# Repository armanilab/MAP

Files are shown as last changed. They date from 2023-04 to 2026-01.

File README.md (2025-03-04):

<<<<<<< HEAD
# MAgnetoPhotometer (MAP)

> Details on system design and full assembly instructions can be found in the preprint: https://arxiv.org/abs/2401.01903

Ready to print 3D files can be found in CAD/stl_files.

The code to be uploaded to the Feather microcontroller can be found in code/MAP_main. 

Visual Data Analysis Program still in progress!

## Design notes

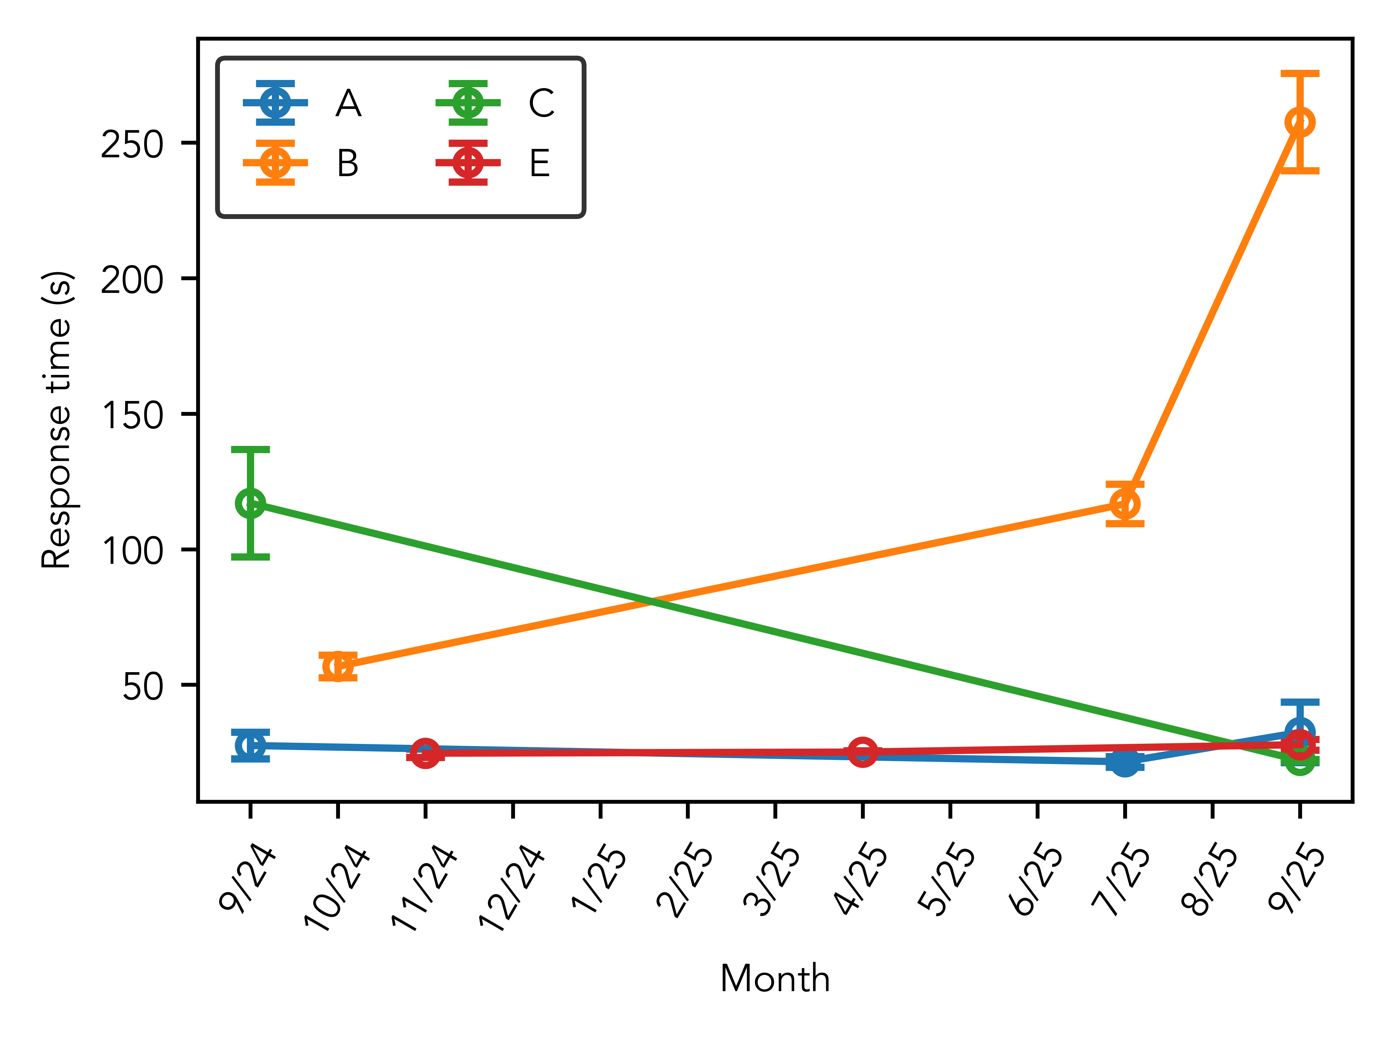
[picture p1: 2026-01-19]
code/model-4.0/plot_resp_times_1.0.png

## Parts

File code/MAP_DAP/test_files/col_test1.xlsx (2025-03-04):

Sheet: Sheet1
File_name | File_location | Date | Daily-num | User | sample | maGnet | Trial-num | Series-tags | Time | Magnet-time | System | Notes
example1 | paper_data/armando-paper | 2022.11.21 |  |  | s1 | 3 | 2 |  | 10:00 | 0:15 | OG | originally named: 3_3_t2 from directory 2022.11.21_working_range_t2
example2 | paper_data/armando-paper | 2022.11.21 |  |  | s2 | 3 | 2 |  | 10:00 | 0:15 | OG | originally named: 4_3_t2 from directory 2022.11.21_working_range_t2

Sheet: samples
ID | Owner | Material | Density | Batch-date | Solvent | Concentration | Dilution-date | Prep-date
s1 | Lexie | Iron oxide |  |  | Water | 0.1
s2 | Arlo | Dynabeads |  |  | PBS | 0.2

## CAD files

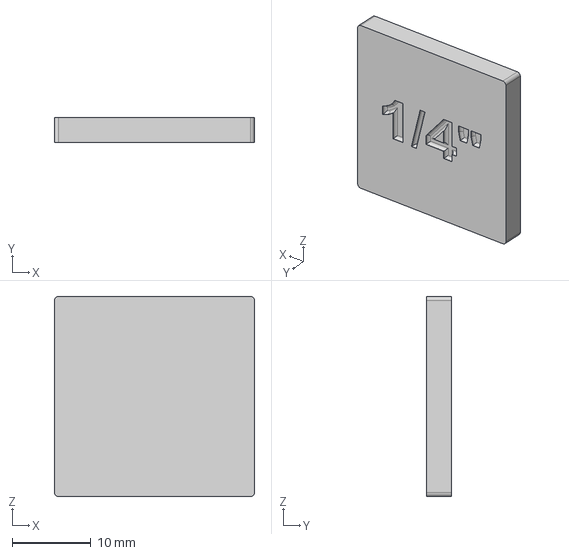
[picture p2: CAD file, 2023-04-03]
CAD/MAP_STEP_files/Magnet_Spacer_1-4.step
25.4 x 3.17 x 25.4 mm

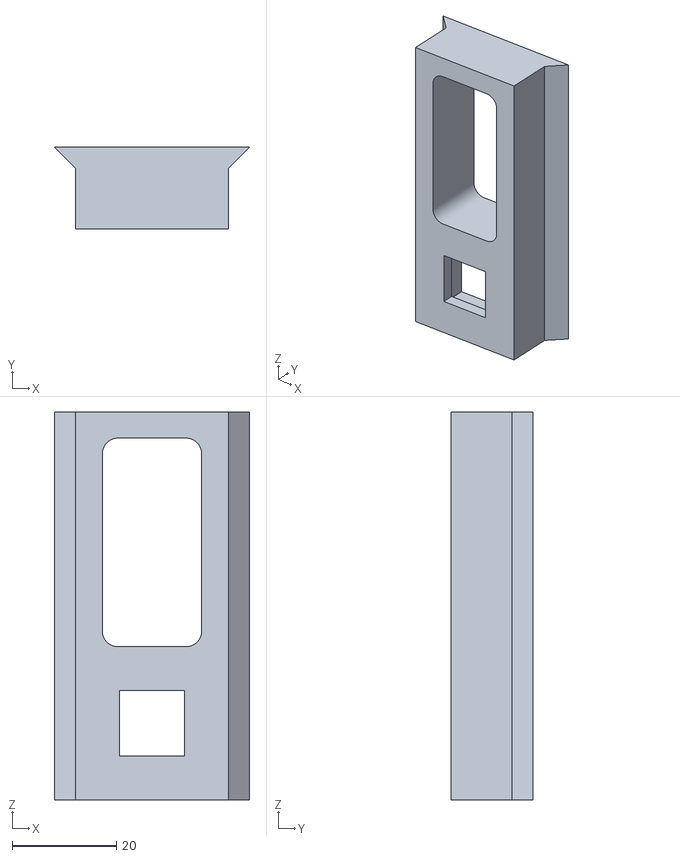
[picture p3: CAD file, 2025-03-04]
CAD/STL/magnet_slider_v1.stl
37.4 x 15.7 x 74.4

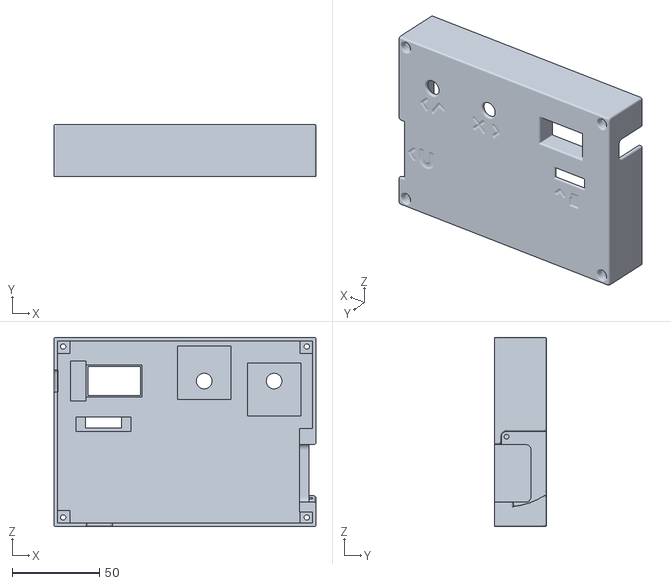
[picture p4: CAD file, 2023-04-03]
CAD/stl_files/top_panel.stl
150.0 x 30.0 x 108.3

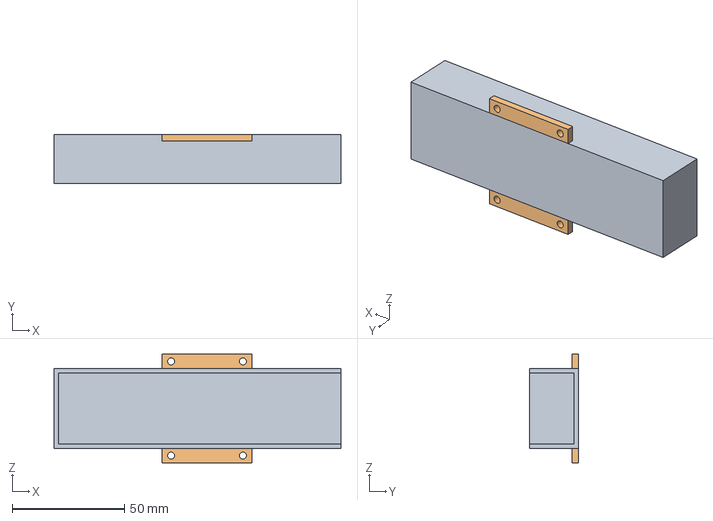
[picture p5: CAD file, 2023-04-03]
CAD/MAP_STEP_files/Magnet_Storage_Cover.step
128.0 x 22.0 x 48.5 mm

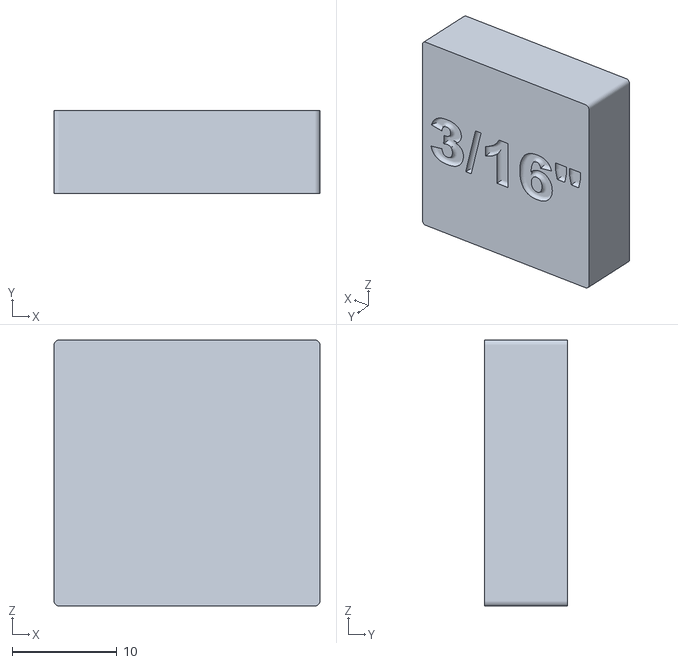
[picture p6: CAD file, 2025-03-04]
CAD/STL/magnet_spacer_3-16_v1.stl
25.4 x 7.94 x 25.4

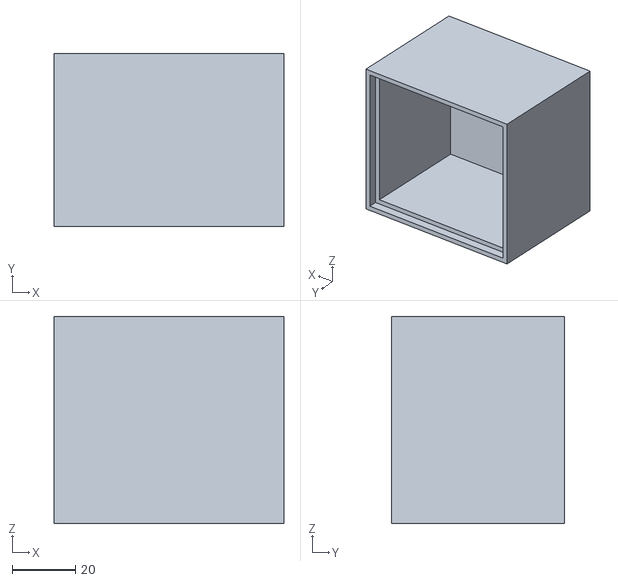
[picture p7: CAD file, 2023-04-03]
CAD/stl_files/stage_cover.stl
73.0 x 55.0 x 65.8

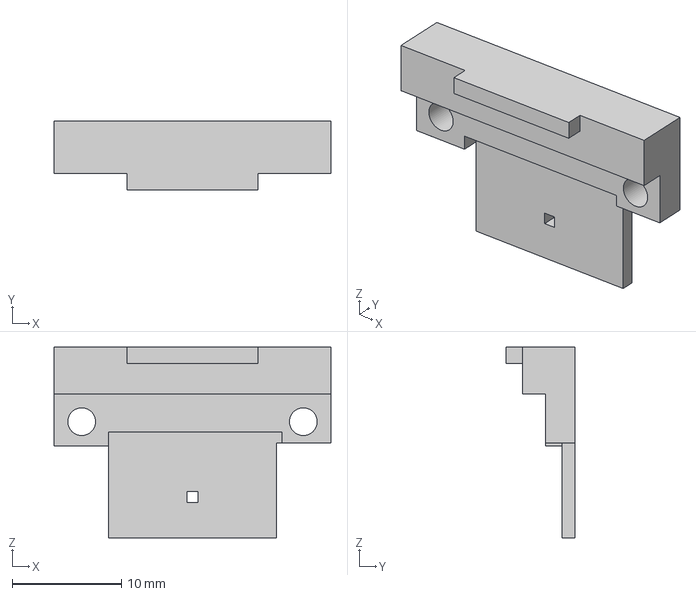
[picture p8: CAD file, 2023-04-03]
CAD/MAP_STEP_files/Sensor_Pinhole.step
25.4 x 6.30 x 17.5 mm

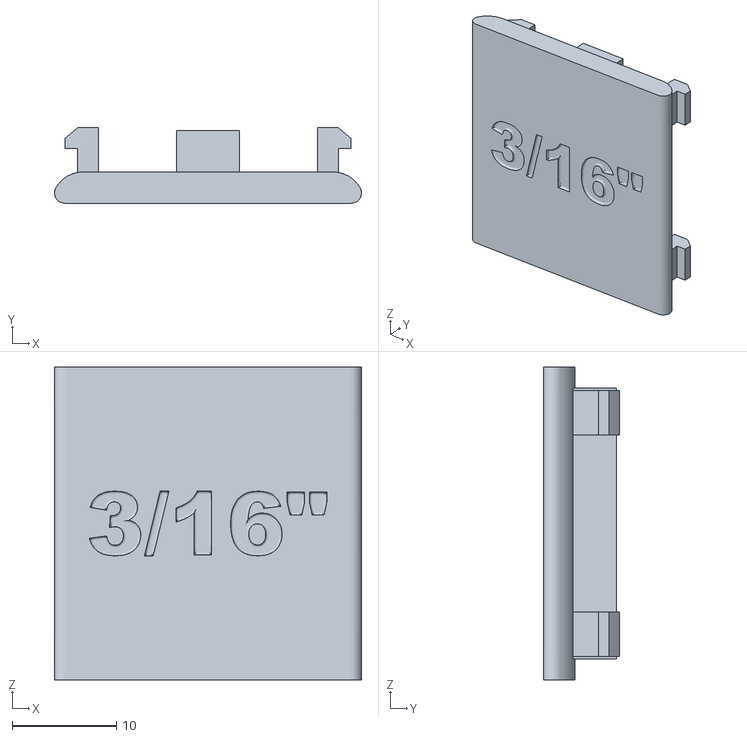
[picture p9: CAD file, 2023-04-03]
CAD/stl_files/magnet_storage_lid_3-16.stl
29.5 x 7.25 x 30.0

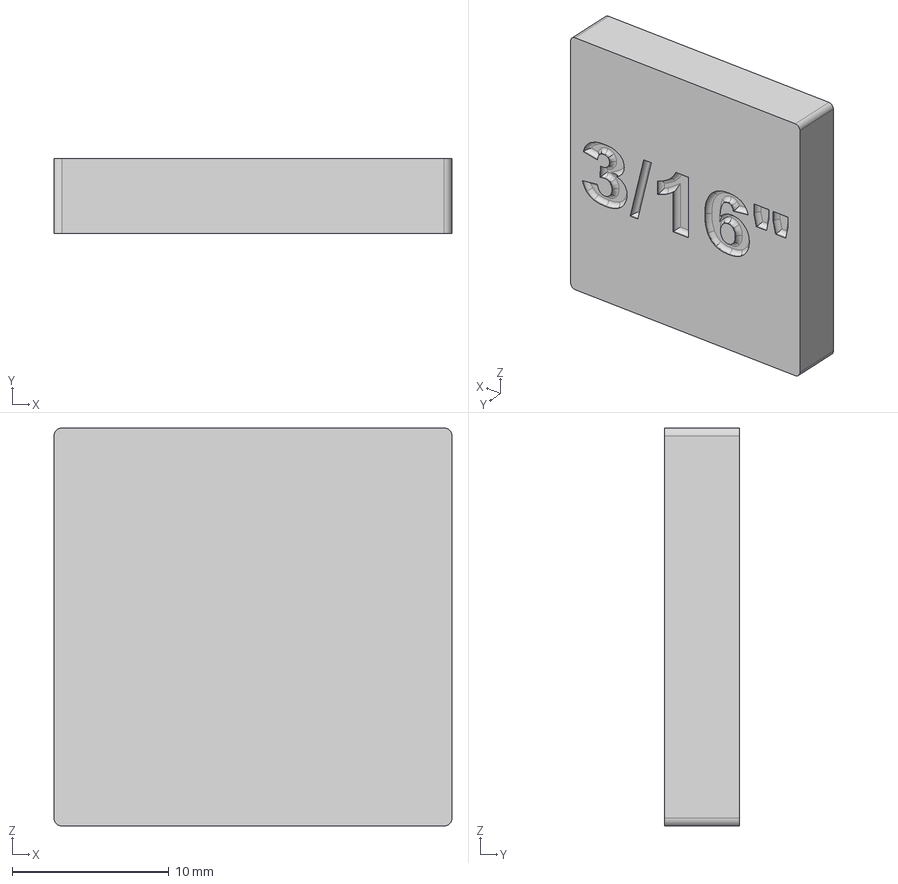
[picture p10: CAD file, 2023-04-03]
CAD/MAP_STEP_files/Magnet_Spacer_3-16.step
25.4 x 4.76 x 25.4 mm

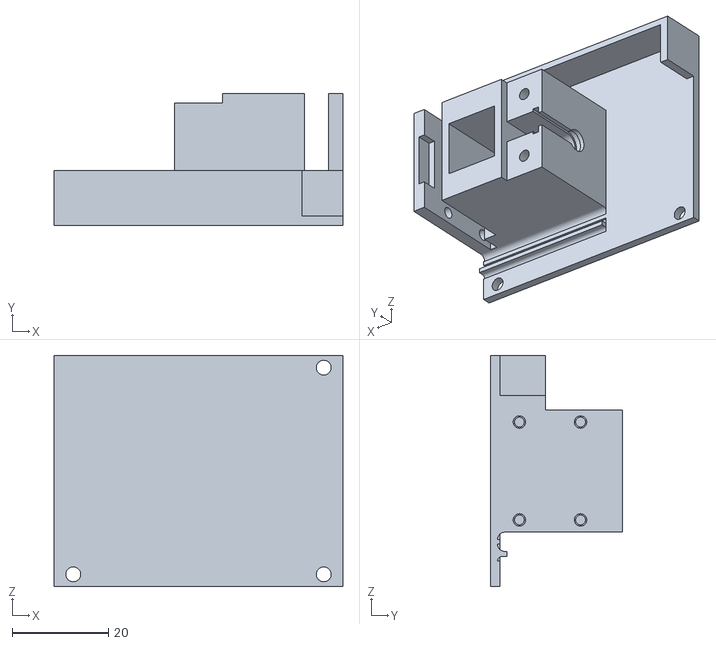
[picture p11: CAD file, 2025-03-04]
CAD/STL/testing_stage_v1.stl
60.0 x 27.5 x 48.0

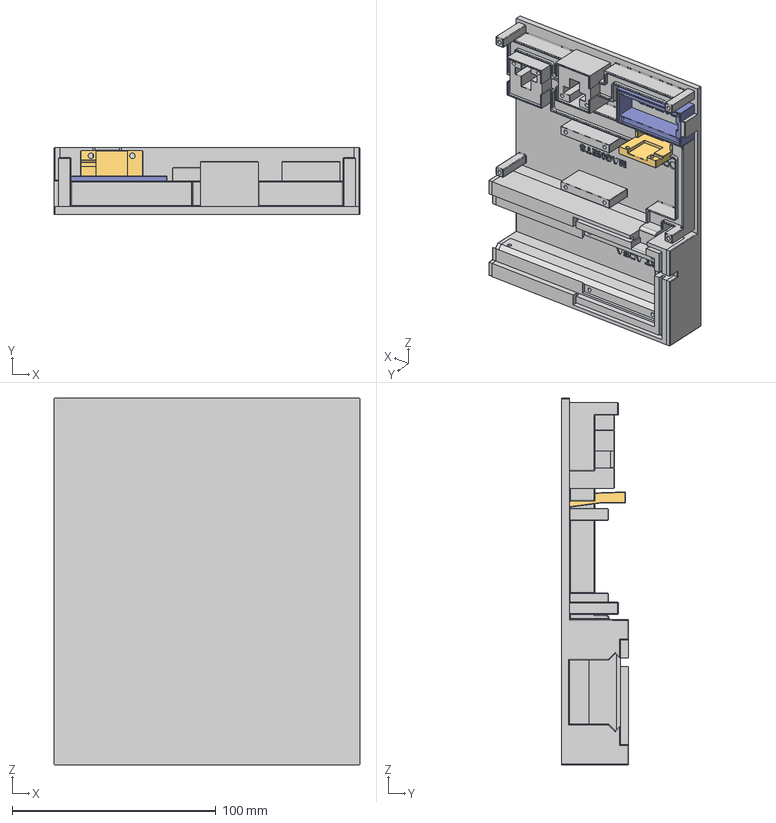
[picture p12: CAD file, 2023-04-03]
CAD/MAP_STEP_files/System_Base.step
150.0 x 33.0 x 180.0 mm
rails
openlog mount
feather mount v2
button mount v2 x 2

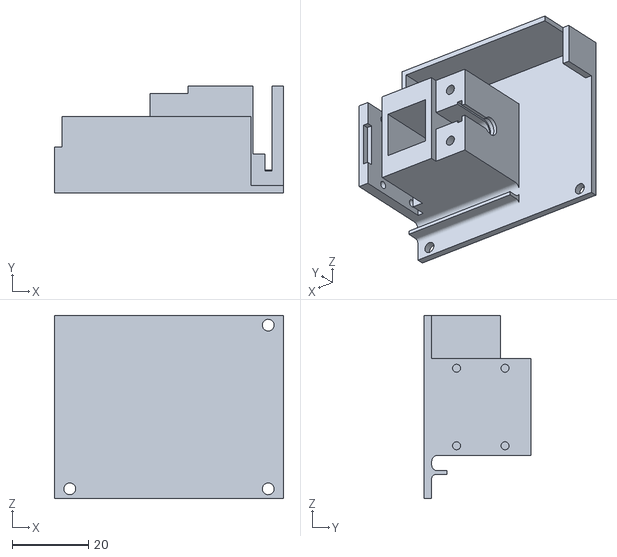
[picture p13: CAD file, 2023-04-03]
CAD/stl_files/testing_stage.stl
60.0 x 28.0 x 48.0

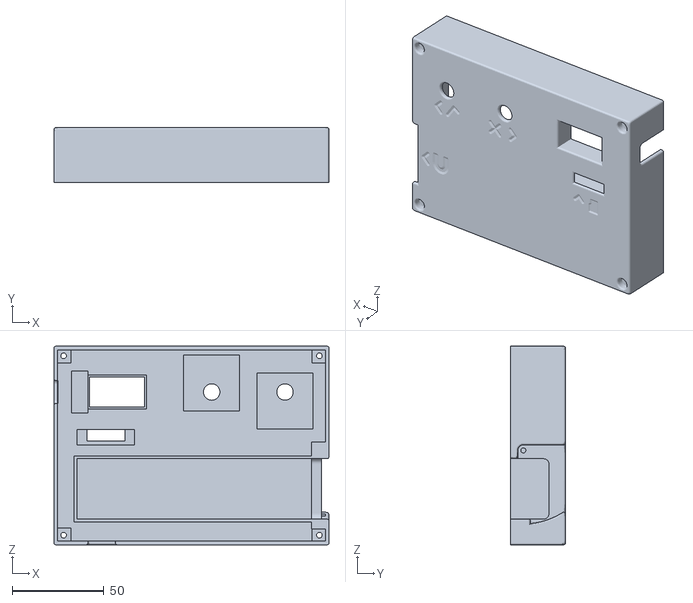
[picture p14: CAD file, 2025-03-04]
CAD/STL/top_panel_v1.stl
150.0 x 30.0 x 108.3

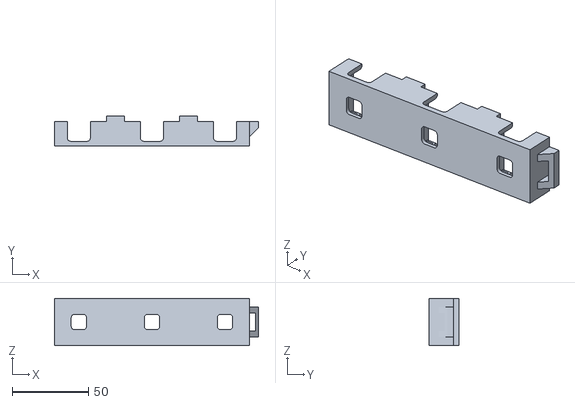
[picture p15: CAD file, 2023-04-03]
CAD/stl_files/magnet_storage_drawer.stl
134.0 x 19.5 x 31.0

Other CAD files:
CAD/STL/magnet_spacer_3-8_v1.stl
CAD/stl_files/magnet_storage_lid_1-4.stl
CAD/STL/stage_cover_v1.stl
CAD/MAP_STEP_files/Top_Panel.step
CAD/MAP_Fusion_files/Led_Cover.f3d
CAD/MAP_Fusion_files/Magnet_Slider.f3d
CAD/MAP_Fusion_files/Magnet_Spacer _1-4.f3d
CAD/MAP_Fusion_files/Magnet_Spacer_3-16.f3d
CAD/MAP_Fusion_files/Magnet_Storage_Cover.f3d
CAD/MAP_Fusion_files/Magnet_Storage_Drawer.f3d
CAD/MAP_Fusion_files/Magnet_Storage_Latch.f3d
CAD/MAP_Fusion_files/Magnet_Storage_Lid_1-4.f3d
CAD/MAP_Fusion_files/Magnet_Storage_Lid_3-16.f3d
CAD/MAP_Fusion_files/Magnet_Storage_Lid_3-8.f3d
CAD/MAP_Fusion_files/Sensor_Pinhole.f3d
CAD/MAP_Fusion_files/Stage_Cover.f3d
CAD/MAP_Fusion_files/System_Base.f3z
CAD/MAP_Fusion_files/Testing_Stage.f3z
CAD/MAP_Fusion_files/Top_Panel.f3z
CAD/MAP_STEP_files/Led_Cover.step
CAD/MAP_STEP_files/Magnet_Slider.step
CAD/MAP_STEP_files/Magnet_Storage_Drawer.step
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

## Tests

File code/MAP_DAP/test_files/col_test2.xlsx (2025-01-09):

Name | Folder | Date | Daily-num | User | Sample_ID | MagnetID | Trial-num | Series-tags | Time | Magnet-time | System | Notes
example1 | paper_data/armando-paper | 2022.11.21 |  |  |  | 3 | 2 |  | 10:00 | 0:15 | OG | originally named: 3_3_t2 from directory 2022.11.21_working_range_t2
example2 | paper_data/armando-paper | 2022.11.21 |  |  |  | 3 | 2 |  | 10:00 | 0:15 | OG | originally named: 4_3_t2 from directory 2022.11.21_working_range_t2

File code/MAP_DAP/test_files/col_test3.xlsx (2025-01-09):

Date | Daily-num | User | Trial-num | Series-tags | Time | Magnet-time | System | Notes
2022.11.21 |  |  | 2 |  | 10:00 | 0:15 | OG | originally named: 3_3_t2 from directory 2022.11.21_working_range_t2
2022.11.21 |  |  | 2 |  | 10:00 | 0:15 | OG | originally named: 4_3_t2 from directory 2022.11.21_working_range_t2

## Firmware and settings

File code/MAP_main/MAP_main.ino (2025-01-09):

/*
 * Driving code for the magnetophotometer (MAP).
 * Written by: Lexie Scholtz
 *             Vic Nunez
 * Created: 2022.09.29
 * Last Updated: 2024.12.12
*/

#include "Arduino.h"
#include <Wire.h>  // needed for open log
#include <Adafruit_Sensor.h>
#include "Adafruit_TSL2591.h"                        // light sensor library
#include "SparkFun_Qwiic_OpenLog_Arduino_Library.h"  // open log library
#include <Adafruit_GFX.h>                            // Core graphics library
#include <Adafruit_ST7789.h>                         // Hardware-specific library for ST7789
#include <SPI.h>
// our libraries:

#include "Display.h"
#include "states.h"
#include "button.h"  // wrapper for the sparkfun library

const int GREEN_I2C_ADDRESS = 0x60;

Adafruit_TSL2591 tsl = Adafruit_TSL2591(2591);  // sensor object
OpenLog open_log;                               // datalogger object
Button red = Button();
Button green = Button(GREEN_I2C_ADDRESS);
Display tft = Display();

States state;

/* IMPORTANT VARIABLES */
// name entry and file name
const uint8_t NAME_LEN = 8;
char file_entry[NAME_LEN + 1] = "********";
String file_name = "";
uint8_t current_name_char = 0;

// run time
const uint8_t TIME_LEN = 4;
int run_time[TIME_LEN] = { 0, 0, 0, 0 };  // nums in the run_time variable [mm/ss]
unsigned long run_time_ms = 0;            // run time converted to ms
uint8_t current_time_char = 0;
// test use
unsigned long start_time = 0;
unsigned long LED_start_time = 0;
unsigned long time_elapsed = 0;
const unsigned long UPDATE_INT = 1000;  // [ms] refresh rate of display during test
unsigned long last_update = 0;          //-UPDATE_INT;
bool ended_early = false;
// avg_slope
int data_points = 40;
int slope_index = 0;
float prev_lux = 1;
bool array_full = false;
int slopes[39];       // *IMPORTANT* If we change # of data points, we must change this number inside of brackets
float time_interval;  // *IMPORTANT* need to find the value this needs to be at
unsigned long prev_time_elapsed = 0;
float cur_slope;

bool updated = false;  // indicates if data for display/serial has been updated

const int RECONNECTION_DELAY = 1000;
const int MSG_TIME = 2000;
const float LIGHT_THRESHOLD = 0.0;

/* NEW FXNS */
char increment_char(char c);
char decrement_char(char c);
bool check_file(String file_name);
bool check_open_log_connection();

void setup() {
  /* HARDWARE SETUP */
  LED_start_time = millis();

  // set up serial communication
  Serial.begin(9600);
  delay(500);

  // set up i2C comms
  Wire.begin();

  // turn on screen
  // turn on backlite
  pinMode(TFT_BACKLITE, OUTPUT);
  digitalWrite(TFT_BACKLITE, HIGH);

  // turn on the TFT / I2C power supply
  pinMode(TFT_I2C_POWER, OUTPUT);
  digitalWrite(TFT_I2C_POWER, HIGH);
  delay(10);

  // initialize tft
  tft.begin();

  // set up buttons
  if (green.init() == false) {
    button_error();
  }

  if (red.init() == false) {
    button_error();
  }

  // set up open log - should this have a check to confirm it worked properly?
  updated = true;
  open_log.begin();
  if (!check_open_log_connection()) {
    logger_error();
  }

  // set up sensor  - confirm connection
  if (!tsl.begin()) {
    sensor_error();
  }

  // configure sensor
  tsl.setGain(TSL2591_GAIN_LOW);
  tsl.setTiming(TSL2591_INTEGRATIONTIME_100MS);

  unsigned long LED_last_update = -UPDATE_INT;
  while (1) {
    int setup_green_status = green.update_status();
    time_elapsed = millis() - LED_start_time;

    // take light measurements
    uint32_t lum = tsl.getFullLuminosity();
    uint16_t ir = lum >> 16;
    uint16_t full = lum & 0xFFFF;
    float lux = tsl.calculateLux(full, ir);

    // if sensor cannot detect any light
    if (full == 0 && ir == 0) {  
      lux = 0;                   
    }

    if (time_elapsed - LED_last_update > UPDATE_INT) {
      // print current intensity
      LED_last_update = time_elapsed;
      Serial.println(lux);
      tft.show_LED_stablization(time_elapsed, lux);
    }
    if (setup_green_status > LONG_HOLD) {  
      // user has indicated LED is ready, progress to next stage
      tft.set_max_lux(lux);
      break;
    }
  }

  // initialize state to name entry
  state = ENTER_TIME;
  updated = true;
}

void loop() {

  // get updated button statuses
  int red_status = red.update_status();
  int green_status = green.update_status();

  // check for button disconnection:
  if (red_status == -1 || green_status == -1) {
    state = ERROR_BUTTON;
  }

  /* TIME ENTRY */
  if (state == ENTER_TIME) {
    // remove this loop when done troubleshooting
    if (updated) {                                     // only send updates if something has actually changed
      tft.show_run_time(run_time, current_time_char);  // call to display function
      updated = false;
    }

    if (green_status > LONG_HOLD) {
      // convert run time to ms and save it
      unsigned long min = run_time[0] * 10 + run_time[1];
      unsigned long sec = run_time[2] * 10 + run_time[3];
      run_time_ms = min * 60000 + sec * 1000;

      updated = true;
      state = ENTER_NAME;

    } else if (green_status > SHORT_HOLD) {
      if (current_time_char < TIME_LEN - 1) {
        current_time_char++;
        updated = true;
      }
    } else if (green_status > CLICK) {
      // increment and decrement time digits
      if (current_time_char == 2) {  // max sec = 60
        run_time[current_time_char] = (run_time[current_time_char] + 1) % 6;
      } else {
        run_time[current_time_char] = (run_time[current_time_char] + 1) % 10;
      }
      updated = true;
    }

    if (red_status > SHORT_HOLD) {
      // user short held red button to go back 1 character
      if (current_time_char > 0) {  // decrement the character index
        current_time_char--;
        updated = true;
      }
    } else if (red_status > CLICK) {
      if (current_time_char == 2) {  // max sec = 60
        run_time[current_time_char] = (run_time[current_time_char] + 6 - 1) % 6;
      } else {
        run_time[current_time_char] = (run_time[current_time_char] + 10 - 1) % 10;
      }
      updated = true;
    }
  } else if (state == ENTER_NAME) { /* NAME ENTRY */
    // update "display" (serial for now) - remove when done troubleshooting
    if (updated) {                                        // only send updates if something has actually changed
      tft.show_file_name(file_entry, current_name_char);  // call to display function
      updated = false;
    }

    // green button input
    if (green_status > LONG_HOLD) {
      if (strcmp(file_entry, "********") == 0) {
        // user must enter a file name
      } else {
        // post processing on entered name
        file_name = String(file_entry);
        file_name.replace("*", "");  // remove *'s from name
        file_name.concat(".txt");    // append .txt to make a text file

        // check file name against existing files
        bool will_overwrite = check_file(file_name);
        if (will_overwrite) {
          // move to NAME_OVERWRITE
          state = NAME_OVERWRITE;
        } else {
          // move to ENTER_TIME state
          state = TEST_READY;
        }
        updated = true;
      }
    } else if (green_status > SHORT_HOLD) {
      // move forward one character
      if (current_name_char < NAME_LEN - 1) {
        current_name_char++;
        updated = true;
      }
    } else if (green_status > CLICK) {
      // increment current char
      file_entry[current_name_char] = increment_char(file_entry[current_name_char]);
      updated = true;
    }  // otherwise, button was not pressed, do nothing

    // react to red button
    if (red_status > LONG_HOLD) {
      state = ENTER_TIME;
      updated = true;
    } else if (red_status > SHORT_HOLD) {
      // go back one character
      if (current_name_char > 0) {
        current_name_char--;
        updated = true;
      }
    } else if (red_status > CLICK) {
      // decrement current character
      file_entry[current_name_char] = decrement_char(file_entry[current_name_char]);
      updated = true;
    }
  } else if (state == TEST_READY) {
    if (updated) {
      tft.show_test_ready(file_name, run_time);  // call to display function
      updated = false;
    }
    if (green_status > LONG_HOLD) {
      // if confirmed ready, prep & move on to actual test

      // if file_name already exists in the directory, remove it
      open_log.removeFile(file_name);
      // create a new file file_name.txt
      open_log.append(file_name);
      // write header lines to the file

      int bytes_written = 0;  // for error catching

      bytes_written += open_log.print("# ");
      bytes_written += open_log.println(file_name);
      bytes_written += open_log.print("# Run time: ");
      bytes_written += open_log.print(run_time[0]);
      bytes_written += open_log.print(run_time[1]);
      bytes_written += open_log.print(" min, ");
      bytes_written += open_log.print(run_time[2]);
      bytes_written += open_log.print(run_time[3]);
      bytes_written += open_log.println(" sec");
      bytes_written += open_log.println("###");

      if (bytes_written == 0) {
        updated = true;
        state = ERROR_LOGGER;
      }

      // flush file - flush() command
      open_log.syncFile();

      // show countdown screen
      tft.show_countdown();

      // record start time
      start_time = millis();

      // move to test in progress state to start test
      state = TEST_IN_PROGRESS;
      tft.clear_screen();
      // TODO: set green LED to blink (use led cycle fxn) ?
    }
    if (red_status > LONG_HOLD) {
      // user long held red button to go back to time entry
      state = ENTER_NAME;
      updated = true;
    }
  } else if (state == TEST_IN_PROGRESS) {
    // stuff that should be running during a test
    time_elapsed = millis() - start_time;

    // take a measurement
    uint32_t lum = tsl.getFullLuminosity();
    uint16_t ir = lum >> 16;
    uint16_t full = lum & 0xFFFF;
    float lux = tsl.calculateLux(full, ir);
    if (lux < LIGHT_THRESHOLD) {  // sensor is not connected
      state = ERROR_SENSOR;
      updated = true;
    }

    if (full == 0 && ir == 0) {  // sensor cannot detect any light
      lux = 0;                   // otherwise this will write nan to file
    }

    // write measurement to file, including time stamp, separated by tab
    int bytes_written = 0;
    float displayed_seconds = time_elapsed / (float)1000;
    bytes_written += open_log.print(displayed_seconds, 3);
    bytes_written += open_log.print("\t");
    bytes_written += open_log.println(lux);
    bytes_written += open_log.syncFile();

    if (bytes_written == 0) {
      Serial.println("bytes written = 0");
      updated = true;
      state = ERROR_LOGGER;
    }

    // TODO: fix the display
    // display stuff
    // finds avg_slope value
    time_interval = time_elapsed - prev_time_elapsed;
    time_interval = time_interval / (float)1000;
    cur_slope = lux - prev_lux;
    cur_slope = cur_slope / (float)time_interval;
    slopes[slope_index] = cur_slope;  // puts current slope value into an array holding the last 4 slope values
    // }
    prev_lux = lux;                        // updates the previous lux value to equal the current lux value
    slope_index++;                         // updates slope_index
    if (slope_index >= (data_points - 2))  // makes sure we don't access array indices that don't exist // subtract by 2?
    {
      slope_index = 0;
      array_full = true;  // makes sure we don't re-enter our base case
    }

    float avg_slope = 0;  // initializes our avg_slope variable
    for (int i = 0; i < (data_points - 2); i++) {
      avg_slope = avg_slope + slopes[i];
    }
    avg_slope = avg_slope / (float)(data_points - 1);  // avg_slope value of last x lux values
    prev_time_elapsed = time_elapsed;

    if (time_elapsed - last_update > UPDATE_INT) {  // in place of the if (updated) statement
      last_update = time_elapsed;
      tft.show_test_in_progress(run_time, time_elapsed, lux, file_name, avg_slope);  // call to display function
    }

    if (red_status > LONG_HOLD || time_elapsed >= run_time_ms) {  // user cancelled test or time is up
      open_log.syncFile();
      state = TEST_ENDED;
      if (time_elapsed < run_time_ms) {
        ended_early = true;
      }
      updated = true;
    }

    // TODO: add red/green button click toggle btwn current vals and the file details screens

  } else if (state == TEST_ENDED) {
    // TODO: dipslay recap stuff
    if (updated) {
      int min = (time_elapsed / 1000) / 60;  // need these variables for display function
      int sec = (time_elapsed / 1000) % 60;
      tft.show_test_ended(file_name, min, sec);  // call to display function
      // red.blink_LED();
      green.blink_LED();
      // indicate test is done and why
      updated = false;
    }

    if (green_status > LONG_HOLD) {
      // if long hold on green button, start new test - go to name entry
      state = ENTER_NAME;
      updated = true;
    }

  } else if (state == ERROR_LOGGER) {
    logger_error();
  } else if (state == ERROR_SENSOR) {
    sensor_error();
  } else if (state == ERROR_BUTTON) {
    button_error();
  } else if (state == NAME_OVERWRITE) {
    // warning of bad stuff

    if (updated) {
      tft.show_enter_name_overwrite(file_name);  // call to display function
      // TODO: update the display
      // note this will only run once when we enter this state, it's not dynamic
      // like the entry states
      updated = false;
    }

    if (green_status > LONG_HOLD) {
      // user long held green to confirm file name
      state = TEST_READY;
      updated = true;
    }
    if (red_status > SHORT_HOLD) {
      // user held red to go back to re-enter file name
      state = ENTER_NAME;
      updated = true;
    }
  }
}

char increment_char(char c) {
  if (c == '*') {
    return 'a';
  } else if (c >= 'a' && c < 'z') {
    return ++c;
  } else if (c == 'z') {
    return '0';
  } else if (c >= '0' && c < '9') {
    return ++c;
  } else if (c == '9') {
    return '!';
  } else if (c == '!') {
    return '_';
  } else {  // c == '_'
    return '*';
  }
}


char decrement_char(char c) {
  if (c == '*') {
    return '_';
  } else if (c == '_') {
    return '!';
  } else if (c == '!') {
    return '9';
  } else if (c > '0' && c <= '9') {
    return --c;
  } else if (c == '0') {
    return 'z';
  } else if (c > 'a' && c <= 'z') {
    return --c;
  } else {  // c == 'a'
    return '*';
  }
}

bool check_file(String file_name) {
  return open_log.size(file_name) > -1;
}

bool check_open_log_connection() {
  return open_log.getStatus() & 1 << STATUS_SD_INIT_GOOD;
}

bool check_sensor_connection() {
  return tsl.begin();
}

bool check_button_connection() {
  return red.check_connection() && green.check_connection();
}

void logger_error() {
  // TODO: add display messages
  tft.show_error_logger();  // call to display function

  // TODO; add test to check for openlog connection
  while (!check_open_log_connection()) {
    delay(RECONNECTION_DELAY);
  }

  tft.show_connection_re_established("Logger");
  delay(MSG_TIME);

  updated = true;
  state = ENTER_NAME;
}

void sensor_error() {
  // TODO: add display messages
  tft.show_error_sensor();  // call to display function

  while (!check_sensor_connection()) {
    delay(RECONNECTION_DELAY);
  }

  tft.show_connection_re_established("Sensor");
  delay(MSG_TIME);

  updated = true;
  state = ENTER_NAME;
}

void button_error() {
  // TODO: add display messages
  tft.show_error_button();

  while (!check_button_connection()) {
    delay(RECONNECTION_DELAY);
  }

  tft.show_connection_re_established("Button(s)");
  delay(MSG_TIME);

  updated = true;
  state = ENTER_NAME;
}

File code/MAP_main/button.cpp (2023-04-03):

/*
 * Code for the magnetophotometer (MAP).
 * class definition: Button
 * Written by: Lexie Scholtz
 *             Vic Nunez
 * Created: 2022.09.29
 * Last Updated: 2023.04.03
*/

#include "Button.h"

// TODO: comment file

Button::Button()
{
  // TODO: add try-catch statement
  qbutton = QwiicButton(); // is this how i do it? i think so?
  was_pressed = false;
  time_of_initial_press = 0;
  i2c_address = 0x6F;
}

Button::Button(int nondefault_i2c_address)
{
  qbutton = QwiicButton();
  was_pressed = false;
  time_of_initial_press = 0;
  i2c_address = nondefault_i2c_address;
}

bool Button::init() {
  return qbutton.begin(i2c_address);
}

bool Button::check_connection() {
  return qbutton.isConnected();
}

int Button::update_status()
{
  if (!qbutton.isConnected()) {
    return -1;
  }
  if (qbutton.isPressed()) {
    if (!was_pressed) {
      was_pressed = true;
      time_of_initial_press = millis();
    }
    unsigned long press_length = millis() - time_of_initial_press;
    set_brightness(determine_brightness(press_length));
  } else { // button not pressed
    if (was_pressed) {
      unsigned long press_length = millis() - time_of_initial_press;
      was_pressed = false;
      return press_length;
    }
    qbutton.LEDoff();
  }
  return 0; // if button was either not clicked or clicked and not released
}

uint8_t Button::determine_brightness(unsigned long press_length) {
  uint8_t brightness = 0;
  if (press_length > LONG_HOLD) {
    brightness = 250;
  } else if (press_length > SHORT_HOLD) {
    brightness = 100;
  } else if (press_length > CLICK) {
    brightness = 10;
  }
  return brightness;
}

void Button::set_brightness(uint8_t brightness_level) {
  qbutton.LEDon(brightness_level);
}

void Button::blink_LED() {
  while (!qbutton.isPressed())
  {
    qbutton.LEDon(250);
    for (int i = 0; i < 10; i++){}
    qbutton.LEDoff();
  }
  qbutton.LEDoff();
}

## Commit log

2022-10-03 added test file for buttons
2022-10-03 added button files
2022-10-03 updated led feedback
2022-10-06 Updated current_char variables
2022-10-12 bug fixes with control
    [magnetometer_main.ino]
2022-10-12 started error checking w/ open log
    [magnetometer_main.ino]
2022-10-12 open log error checking complete
    [magnetometer_main.ino]
2022-10-18 test for light sensor errors
2022-10-18 fixed sensor error loops
    [magnetometer_main.ino]
2022-10-19 Couple edits to main and display class
2022-10-20 added button reconnection stuff
2022-10-20 Should now work with current lux vals
    - need to change time_interval values between lux readings
    - Added a "go-back" option on test_ready screen
2022-11-03 Updated amount of data points
    Trying to reduce noise
    [magnetometer_main.ino]
2022-11-17 Revert "Commented out Serials: I believe?"
    This reverts commit 6f8b812d908f64754902a6405c8c43d1ead64519.
    [magnetometer_main.ino]
2023-01-20 Update button.h
    Will Lexie see this?
2023-01-22 started data visualization program; implemented filter by series ID
2023-02-01 Turns on the green LED when test is done!
2023-02-21 updated filtering, concentration plot
2023-03-13 Light curve analysis scripts
    LightFucntions.py
    -- has all the functions from the mathematical model as well as some data adjustment functions
    multi_LA.py
    -- is the script that actually analyzes the magnetometer data
    --Will need to have an empty repository named "plots" to store the plots of the log(1/T) data with the fits
    -- Will need a file which holds either a single, or multiple sets of the magnetometer data
    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
2023-03-22 added script to change button i2c address
2023-03-23 LED Warming Up Screen
    - added first screen that has timer for LED warm up time
    - Can long hold green to move on from the screen
2023-04-03 added 3d printing files
    [led_cover.stl, magnet_slider.stl, magnet_spacer_1-4.stl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]
2023-04-03 Adding CAD Folder
    Adding CAD Folder with STEP files and F3z/F3d files
    [Led_Cover.f3d, Led_Cover.step, Magnet_Slider.f3d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]
2023-04-03 Moved stl Files to CAD folder
    [led_cover.stl, magnet_slider.stl, magnet_spacer_1-4.stl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]
2023-04-03 Delete stl_files directory
    Deleting bc they now exist within CAD folder
    [led_cover.stl, magnet_slider.stl, magnet_spacer_1-4.stl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]
2023-04-12 fixed bug when lux = 0
    [MAP_main.ino]
2023-04-13 Added current lux value to LED Warming Up
2023-06-04 added first attempt at filteringi
2023-10-13 temporary changes
    [Led_Cover.f3d, Led_Cover.step, Magnet_Slider.f3d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]
2023-11-30 fixed B_r constant, magnet thickness errors
2023-12-06 added jack's code with B_r bug fix, calibration fix
2023-12-06 fixed bug related to unfixing magnet thickness
2024-01-02 updated magnet importer
2024-01-06 added no magnet option to avoid key errors
2024-01-08 updates to CAD directories
    [Led_Cover.step, Magnet_Slider.step, Magnet_Spacer_3-16.step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]
2024-01-08 re-added CAD files
    [Led_Cover.f3d, Led_Cover.step, Magnet_Slider.f3d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]
2024-01-08 renamed file
    [Magnet_Spacer_1-4.step]
2024-08-28 fixed bug for sensor connection failure and also back button bug during time setting
    [MAP_main.ino]
2024-08-28 reorderd control flow
2024-08-28 added test countdown and fixed bug with display of file names
    [MAP_main.ino]
2024-09-10 updated drag force to approx of cylindrical rod, changed fit arguments to improve fit
2025-01-09 initial MAP-DAP v2 files
    [col_test1.xlsx, col_test2.xlsx, col_test3.xlsx]
2025-01-11 updates to how file manager and main gui class interact, implemented initial setup screen: log and sample file selections
2025-01-11 reformatted magnet files to .json files
2025-02-13 initial STL files
    [led_cover_v1.stl, magnet_slider_v1.stl, magnet_spacer_1-4_v1.stl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]
2025-02-13 initial version of device code
2025-03-04 added sample df merge to file list
    [col_test1.xlsx]
2025-04-08 added initial file log preview and add/remove button capabilities
2025-09-29 model modified to account for magnetic core + non-magnetic shell to find mag sus of magnetic material only
